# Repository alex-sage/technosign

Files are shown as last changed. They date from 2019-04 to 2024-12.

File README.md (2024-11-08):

# technosign
  _The Technopark LED Sign Project_

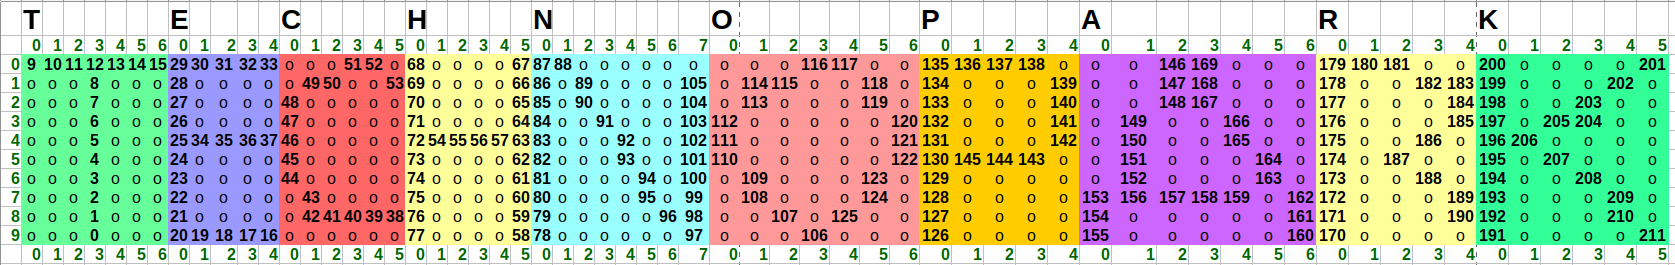
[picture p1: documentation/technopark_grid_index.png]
sign


* documentation - layout and mapping documents

* LED_RTOS - Real Time OS for the LED strip
* LED_Tester - First sign class

* index_letters - First go at usign the LED and some fun functions.
* set_led - set a single LED by serial control; for debugging.
* test_letters - rudimentary test of the strip.

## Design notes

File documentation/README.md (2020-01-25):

## Documentation of various kind

* led_arrangement.jpg - The original ground truth for the LED layout and connection order.

* technopark_grid.svg - a grid mapping of the LEDs, by id
* technopark_grid.png - bitmap view of the .svg

* technopark_grid.ods - the same grid mapping as the .svg drawing, but this is structured table layout in a spreadsheet
* technopark_grid.csv - intermediate .csv export of the spreadsheet.
* format_grid.py - converts the .csv to C code
* technopark_grid.h - output from the format_grid.py (will be moved)

* technoir.jpg - inspiration

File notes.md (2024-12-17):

<<<<<<< HEAD
# 2024-12-17

Final handover. The sign is on top of the cupboards in the Dev room, running the ESP32 board.

We had to cut out one LED on the O, because it was broken. This was reflected in the letter indexes in sign.yml of this MR, however, documentation, C++ code has not been updated.
=======
# 2024-11-21

Freecad models for 3D printing the brackets to hang up the power supply and MC boards.
>>>>>>> ccb4f2ec67bafa8d346372fb47ac6c4701b7f68d

# 2024-11-11

Hooked up the ESP32 to the sign, and got a number of things to work. [See details here](esp32/notes.md).

# 2024-11-08

ESP32: Just trying stuff out for now.

# 2024-11-08

The full sign; all letters, all 211 LEDs work again.

It seems like there is a short somewhere near the H or N. When the cables and letters are moved around there, there is a cut or short. Also, while touching the sign, there's often a small shock. The cables are touching the sign somewhere.

To debug, we have a few useful tools:

- [technopark_grid_index.png](documentation/technopark_grid_index.png): Shows the layout of the LEDs and their index.
- `set_led`: This takes an int on the terminal and blinks the corresponding LED index (the Arduino has to be connected to the computer)
- `test_letters`: Has a hardcoded `LED_COUNT` and cycles the LEDs up to that point. Can be useful when something only works half-way.
- `index_letters`: Once everything works, this cycles the whole sign in different colors.

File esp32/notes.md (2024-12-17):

# 2024-12-17

ESP32 board works. sign.yml updated to reflect broken LED (see ../notes.md).

# 2024-11-11

Hooked up the ESP32 to the sign, and got a number of things to work. The `light` component can address the LED strip, using the "WS2812x" variant driver and "RGB" color ordering. It's connected to PIN IO12 (which is in the same location as the pin 8 on the Arduino).

Furthermore, the `light` section can have multiple `partition` parts, so each letter has been assigned to a segment. They can now be controlled individually. However, the default color / gamma setting is odd. It looks purple/pink.

Also, the Addressable Light (display) component works (although, commented out right now). It is targeted towards a grid display, which is of course not quite what we have. However, that was interesting, was that we can import C++ code (see the top of the sign.yml file), so the old matrix we had could be used directly in the `pixel_mapper` config.

Note that, I think the letters N and O have been pushed in a rotated manner, so that the index no longer match up.

See (sign.yaml)[sign.yaml] for details and (esphome_web_ui.png)[esphome_web_ui.png] for the UI.

# 2024-11-08

First attempt with the ESP32. As of writing, not connected to the LED strip yet, but it works on the local wifi (and wired office network). (Note the replaced passwords and names in the sign.yml in this directory).

Also note, that these Docker based scripts cannot be used on a NFS based directory, so not over the NAS, home directory, etc.

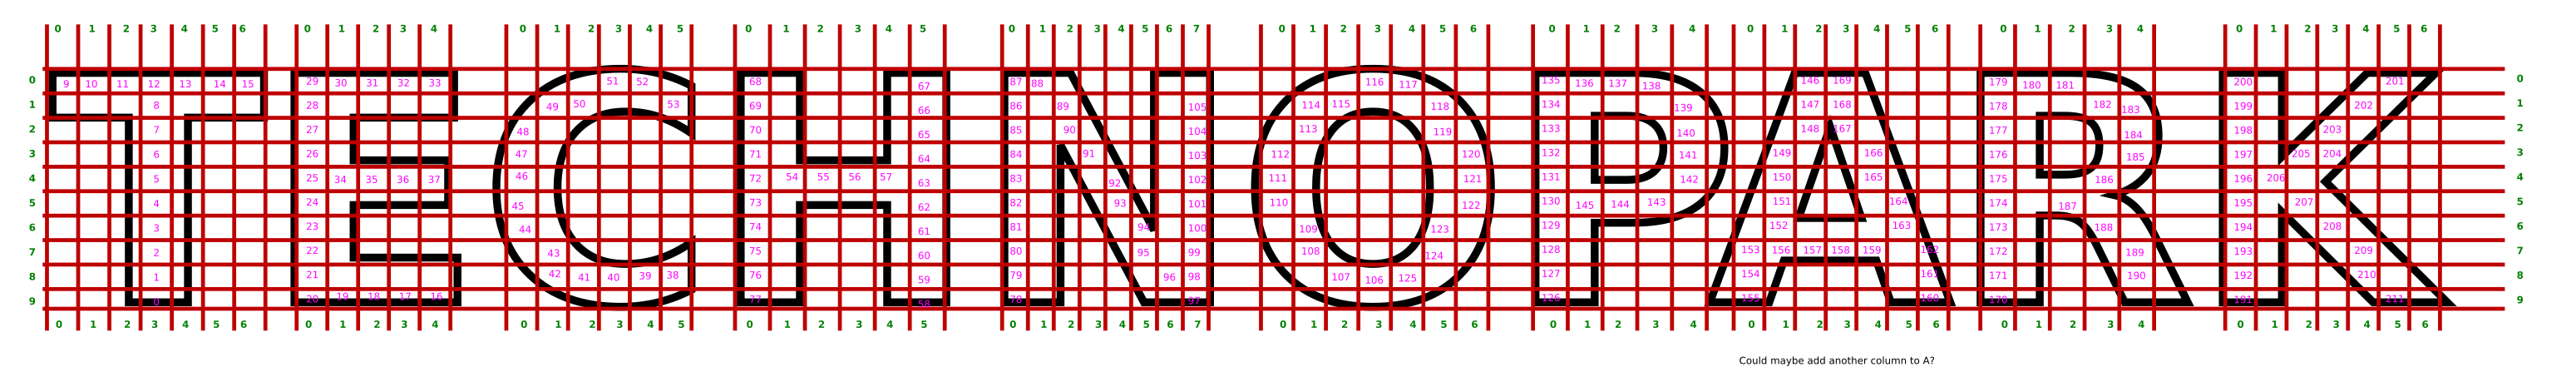
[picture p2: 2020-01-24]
documentation/technopark_grid.png

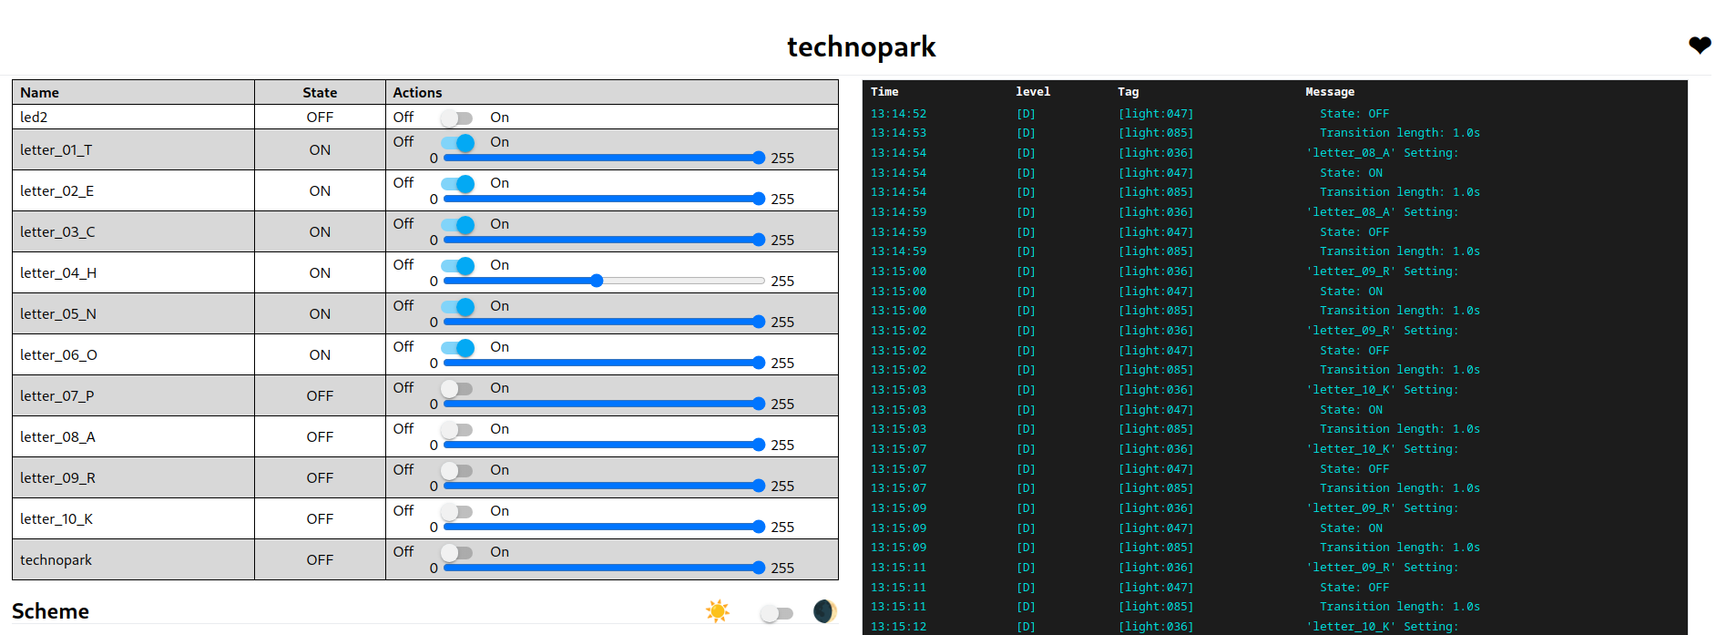
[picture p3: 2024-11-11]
esp32/esphome_web_ui.png

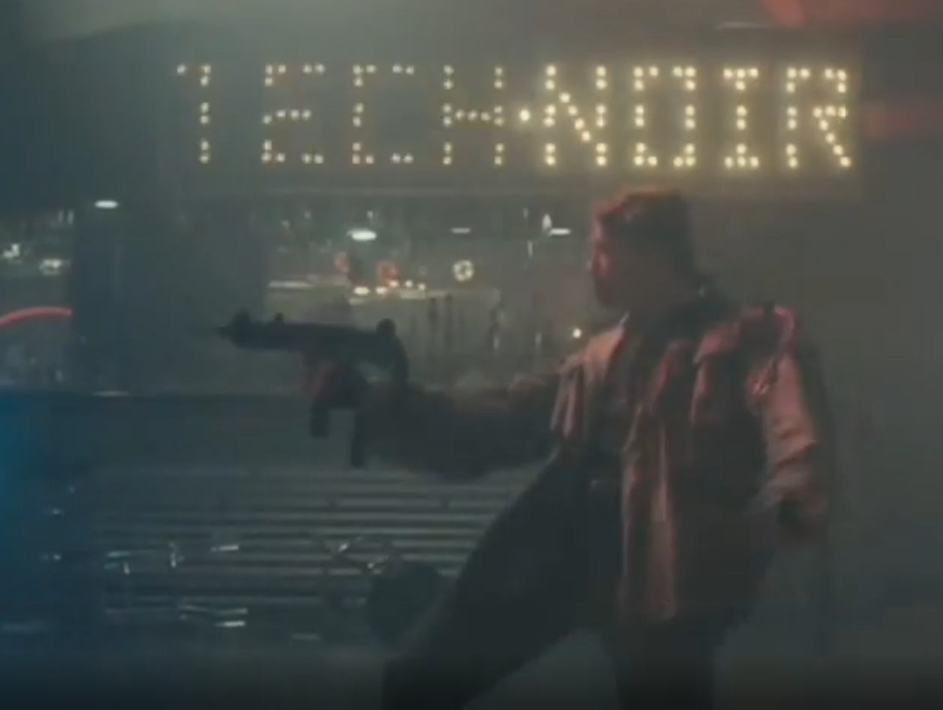
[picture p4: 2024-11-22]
documentation/technoir.png

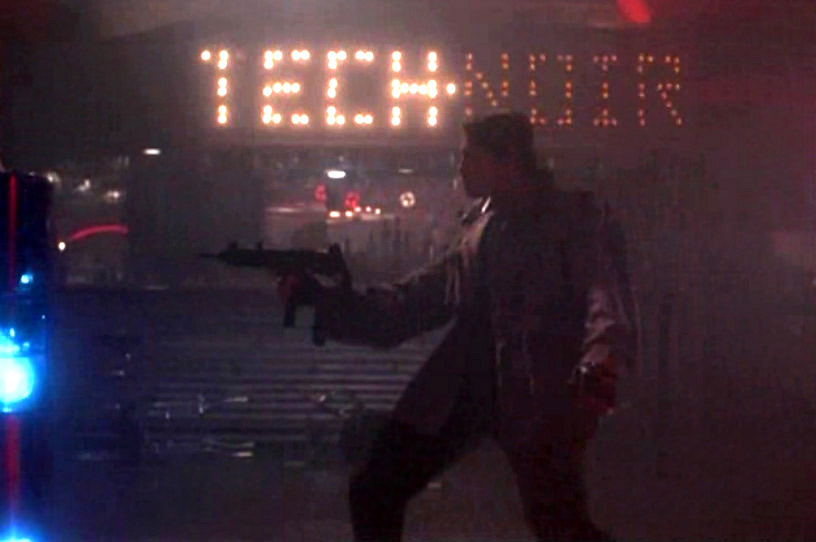
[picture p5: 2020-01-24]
documentation/technoir.jpg

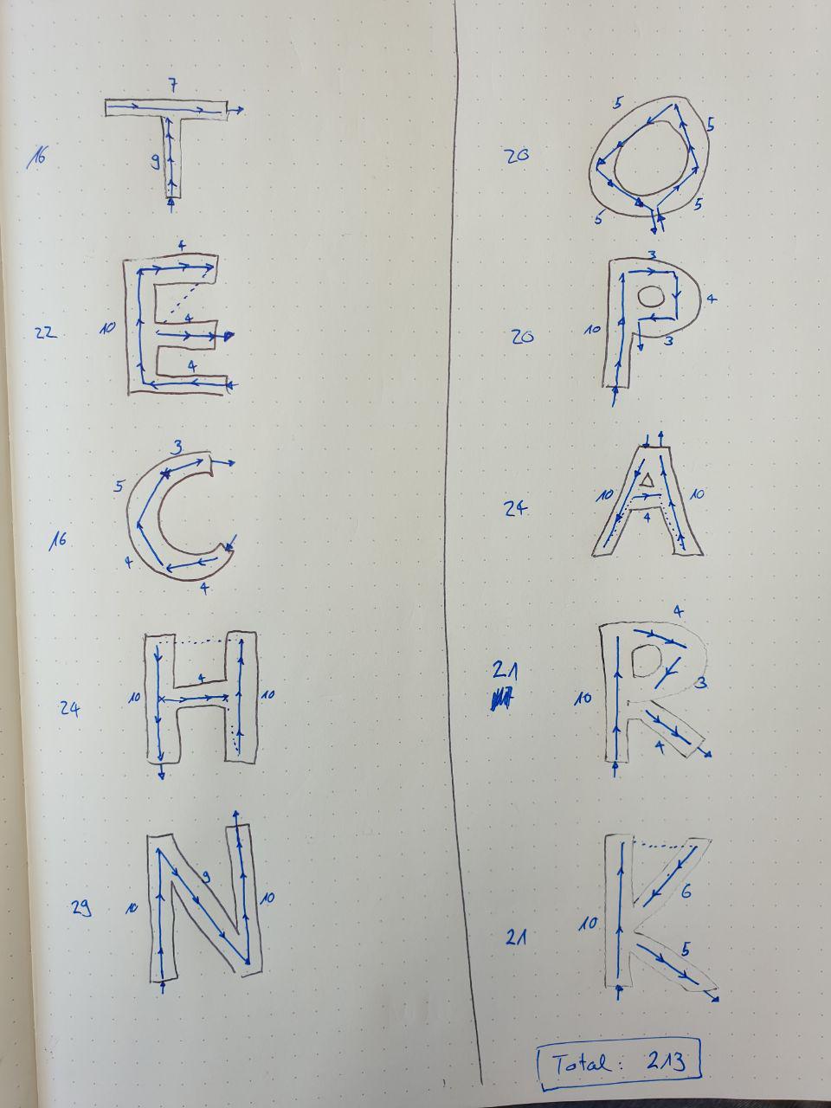
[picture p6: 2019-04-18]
documentation/led_arrangement.jpg

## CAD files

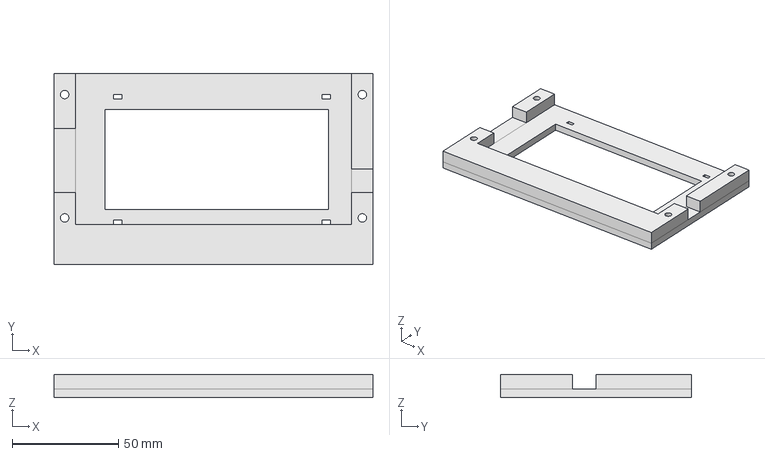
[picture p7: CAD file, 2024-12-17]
brackets/power3.FCStd
150.0 x 90.0 x 11.0 mm

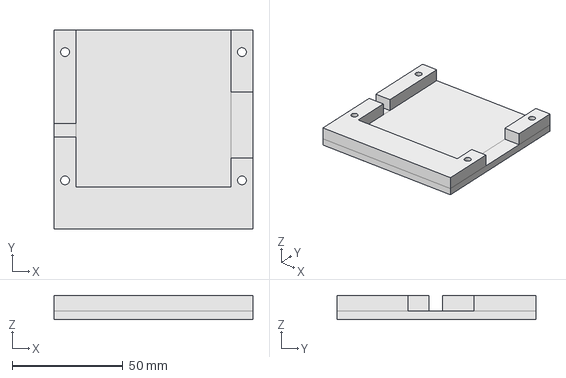
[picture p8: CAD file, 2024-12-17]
brackets/power_split.FCStd
90.0 x 90.0 x 11.0 mm

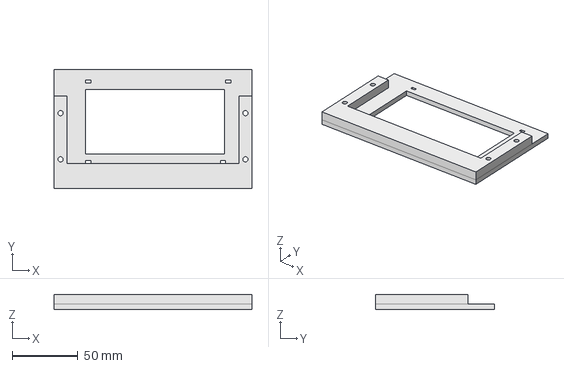
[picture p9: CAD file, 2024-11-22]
brackets/power2.FCStd
150.0 x 90.0 x 11.0 mm

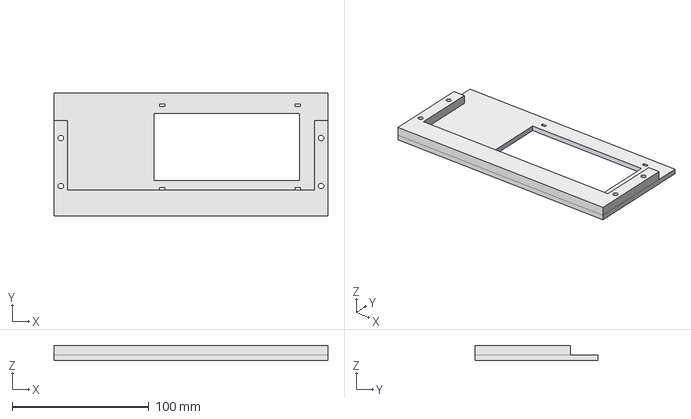
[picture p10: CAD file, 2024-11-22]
brackets/power1.FCStd
200.0 x 90.0 x 11.0 mm

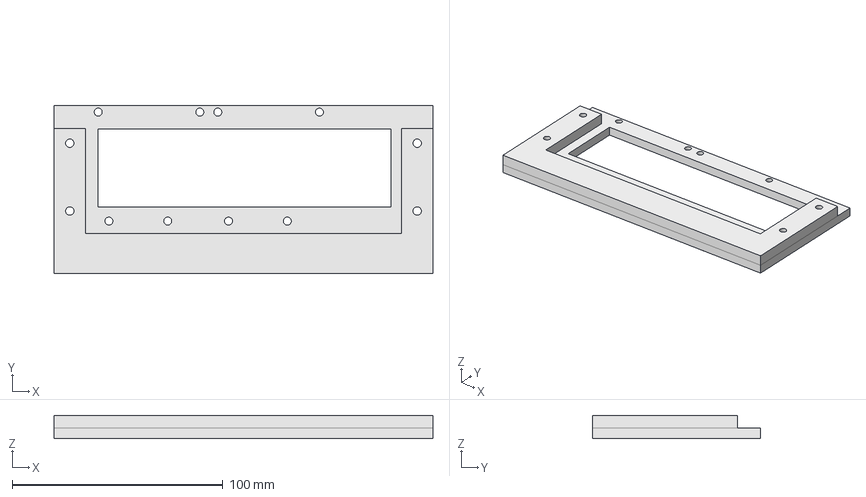
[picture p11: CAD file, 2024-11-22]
brackets/backplate2.FCStd
180.0 x 80.0 x 11.0 mm

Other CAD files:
brackets/power_split1.stl
brackets/power3.stl

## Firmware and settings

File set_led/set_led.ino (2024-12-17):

/* Sets a single LED based on Serial input.
 * Intended for locating the grid points.
 */

#include <PololuLedStrip.h>

// Create an ledStrip object and specify the pin it will use.
PololuLedStrip<8> ledStrip;

// Create a buffer for holding the colors (3 bytes per color).
const int LED_COUNT=212;
rgb_color colors[LED_COUNT];

void setup()
{
  // Start up the serial port, for communication with the PC.
  Serial.begin(19200);
  Serial.println("Ready to receive colors.");

        // Update the colors buffer.
        rgb_color blank;
        blank.red = 255;
        blank.green = 255;
        blank.blue = 255;
        
      for(uint16_t i = 0; i < LED_COUNT; i++)
      {
        colors[i] = blank;
      }

      // Write to the LED strip.
      ledStrip.write(colors, LED_COUNT);

}


rgb_color rgb(uint16_t r, uint16_t g, uint16_t b)
{
    rgb_color c;

    // That's right. The red and green in the rgb_color object is reversed for our strip.
    c.red = g;
    c.green = r;
    c.blue = b;

    return c;
}

const rgb_color BLANK = rgb(0, 0, 0);
const rgb_color WHITE = rgb(100, 100, 100);
const rgb_color RED = rgb(100, 0, 0);
const rgb_color GREEN = rgb(0, 100, 0);
const rgb_color BLUE = rgb(0, 0, 100);
const rgb_color PURPLE = rgb(100, 0, 100);
const rgb_color YELLOW = rgb(100, 100, 0);

const rgb_color color_loop[5] = { BLANK, WHITE, RED, GREEN, BLUE };
int color_idx = 0;
int idx = 0;

void loop()
{
  if (Serial.available())
  {
    idx = Serial.parseInt();
    
    while (Serial.available()) {
      Serial.read();
    }
 } else {
    delay(500);
 }

    color_idx++;
    color_idx %= 5;


    for(uint16_t i = 0; i < LED_COUNT; i++)
    {
    	if (i == idx) {
              colors[i] = color_loop[color_idx];
    	} else {
    	  colors[i] = BLANK;
    	}
    }

    ledStrip.write(colors, LED_COUNT);

    
  
}

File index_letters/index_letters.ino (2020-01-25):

/**
 * Concept for adressing the letters.
 */

#include "common.h"
#include "index.h"

void setup()
{
    Serial.begin(19200);

    all(rgb(0, 0, 0));
    write();
    delay(100);

    leds[0] = WHITE;
    write();
    delay(1000);
}

void loop()
{
    int d1 = 100;
    oneByOne(RED, d1);
    oneByOne(GREEN, d1);
    oneByOne(BLUE, d1);

    int d2 = 30;
    snake(RED, d2);
    snake(PURPLE, d2);
    snake(BLUE, d2);
    snake(GREEN, d2);
    snake(YELLOW, d2);
}

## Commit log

2019-04-18 added image with led counts
2020-01-24 Set a single LED by index
2020-01-24 Found the missing LED: The N
    [index_letters.ino, set_led.ino]
2020-01-25 Got the grid array
    [technopark_grid.csv, technopark_grid.ods]
2020-01-25 Fix the N
    One LED was removed from the N
2024-11-08 Trying ESP32
2024-11-11 All RGB template buttons
2024-11-22 bracket model in freecad
    [backplate2.FCStd]
2024-11-22 power bracket draft
    [power1.FCStd, power2.FCStd]
2024-11-22 5V adapter
    [power3.FCStd]
2024-11-22 power brackets
    [power3.FCStd, power3.stl, power_split.FCStd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]
